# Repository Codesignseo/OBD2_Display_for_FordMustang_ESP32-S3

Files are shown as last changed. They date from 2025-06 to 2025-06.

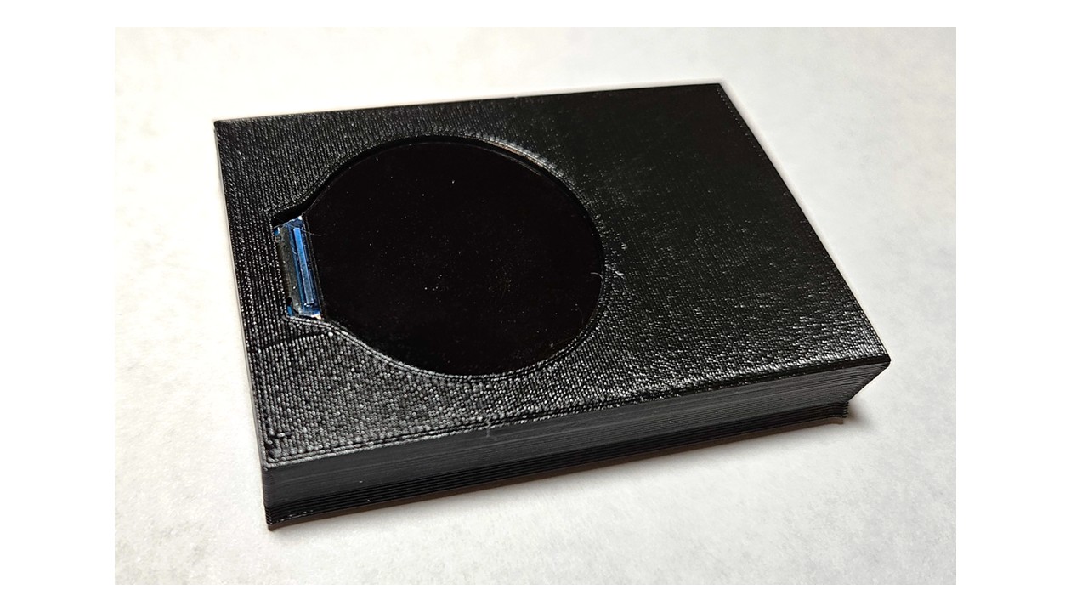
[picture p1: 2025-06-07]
Images/Design1.jpg

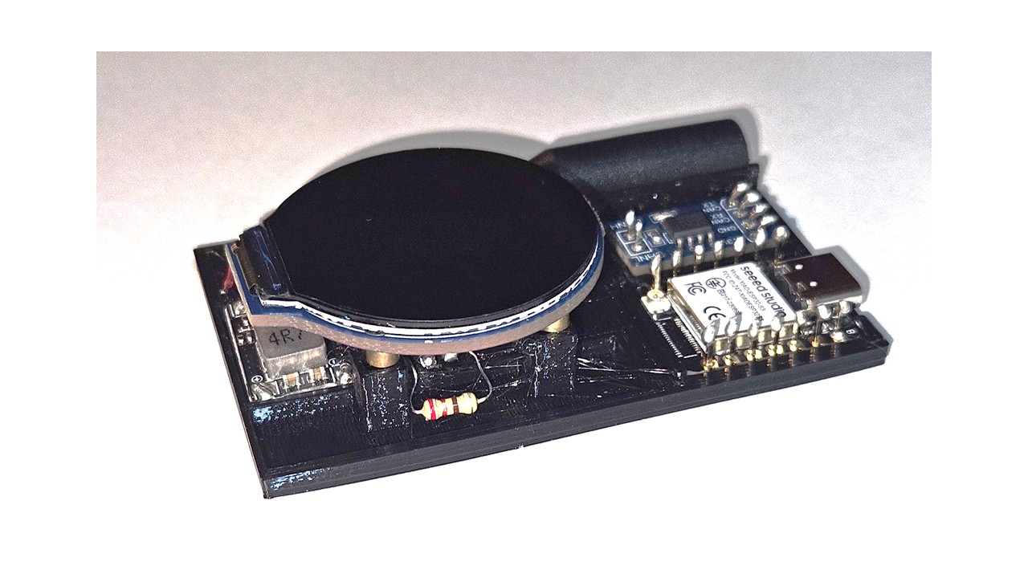
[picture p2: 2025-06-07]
Images/Design4.jpg

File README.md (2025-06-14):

# OBD2 Display for Ford Mustang ESP32-S3 🚗💨




Welcome to the OBD2 Display for Ford Mustang project! This Arduino-based project provides a sleek interface for displaying OBD2 data on a round LCD display. It is specifically designed for the 2016 Ford Mustang Ecoboost, offering real-time information about the currently selected gear and a simple gear shift indicator.

## Table of Contents

1. [Introduction](#introduction)
2. [Features](#features)
3. [Getting Started](#getting-started)
   - [Hardware Requirements](#hardware-requirements)
   - [Software Requirements](#software-requirements)
   - [Installation Instructions](#installation-instructions)
4. [Usage](#usage)
5. [Wiring Diagram](#wiring-diagram)
6. [Contributing](#contributing)
7. [License](#license)
8. [Contact](#contact)

## Introduction

The OBD2 Display for Ford Mustang project aims to enhance your driving experience by providing essential vehicle data at a glance. With this project, you can monitor your gear selection and RPM in real-time, ensuring you stay informed while on the road.

## Features

- **Real-time Gear Display**: See your current gear selection directly on the LCD.
- **Gear Shift Indicator**: Get a visual cue for when to shift gears.
- **Compact Design**: Fits seamlessly in your vehicle without cluttering the dashboard.
- **Easy Installation**: Simple wiring and setup make it accessible for all skill levels.

## Getting Started

To get started with the OBD2 Display for Ford Mustang project, follow these steps.

### Hardware Requirements

- **ESP32-S3**: The main microcontroller for this project.
- **Round LCD Display (GC9A01)**: For displaying the gear and RPM information.
- **OBD2 Adapter (SN65HVD230)**: To connect to the vehicle's OBD2 port.
- **MOSFET**: For controlling power to the display.
- **Wires and Connectors**: For making connections between components.
- **XIAO ESP32-S3**: A compact version of the ESP32-S3 for space-saving.

### Software Requirements

- **Arduino IDE**: Download and install the latest version of the Arduino IDE from the [official website](https://www.arduino.cc/en/software).
- **ESP32 Board Support**: Install the ESP32 board support in the Arduino IDE.
- **Libraries**: You will need the following libraries:
  - `OBD2 Library`
  - `GC9A01 Library`
  
### Installation Instructions

1. **Clone the Repository**: 
   Open your terminal and run:
   ```
   git clone https://github.com/Codesignseo/OBD2_Display_for_FordMustang_ESP32-S3.git
   ```
2. **Open the Project in Arduino IDE**: Navigate to the cloned folder and open the `.ino` file in the Arduino IDE.
3. **Install Required Libraries**: Go to `Sketch` > `Include Library` > `Manage Libraries`, and search for the required libraries mentioned above. Install them.
4. **Connect Your ESP32-S3**: Use a USB cable to connect your ESP32-S3 to your computer.
5. **Select the Correct Board**: In the Arduino IDE, go to `Tools` > `Board` and select `ESP32-S3`.
6. **Upload the Code**: Click on the upload button in the Arduino IDE to upload the code to your ESP32-S3.
7. **Download the Releases**: For the latest version of the software, visit the [Releases section](https://github.com/Codesignseo/OBD2_Display_for_FordMustang_ESP32-S3/releases) to download and execute the latest build.

## Usage

Once the setup is complete, you can start using the OBD2 Display. The LCD will automatically show the current gear and RPM as you drive. Adjust the display settings as needed through the Arduino IDE.

## Wiring Diagram

Here is a simple wiring diagram to help you connect the components:

```
ESP32-S3       Round LCD (GC9A01)
-----------------------------------
  GND  ------------------  GND
  3.3V ------------------  VCC
  GPIO23  --------------  SCL
  GPIO22  --------------  SDA

ESP32-S3       OBD2 Adapter (SN65HVD230)
------------------------------------------
  GND  ------------------  GND
  TX   ------------------  RX
  RX   ------------------  TX
```

## Contributing

We welcome contributions to this project. If you would like to contribute, please fork the repository and submit a pull request. Make sure to follow the coding standards and include tests for any new features.

## License

This project is licensed under the MIT License. See the [LICENSE](LICENSE) file for more details.

## Contact

For any questions or feedback, please reach out via the GitHub issues page or contact the repository owner directly.

Thank you for your interest in the OBD2 Display for Ford Mustang project! For the latest updates and releases, be sure to check the [Releases section](https://github.com/Codesignseo/OBD2_Display_for_FordMustang_ESP32-S3/releases).

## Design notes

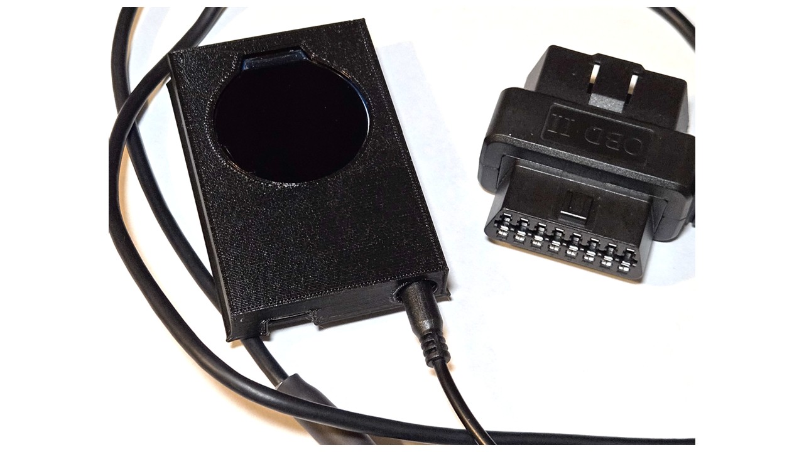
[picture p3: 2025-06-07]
Images/Design2.jpg

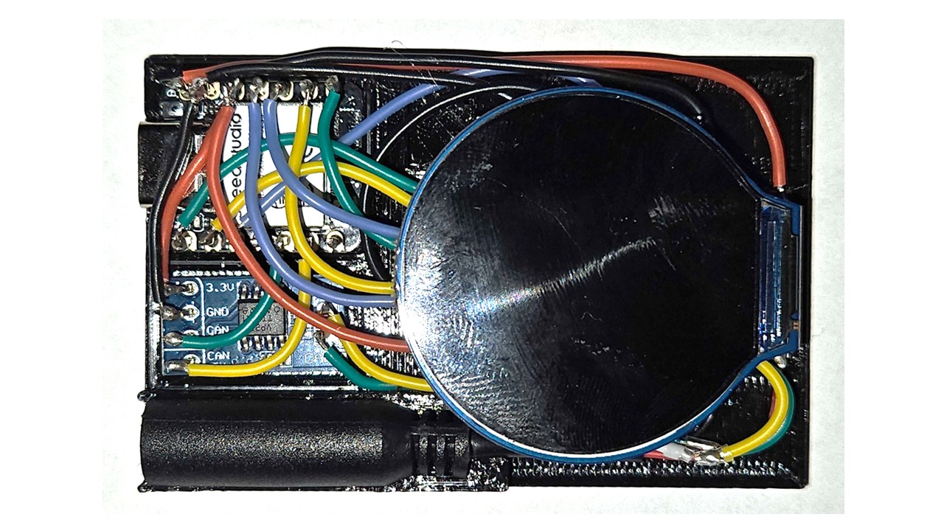
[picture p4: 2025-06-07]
Images/Design5.jpg

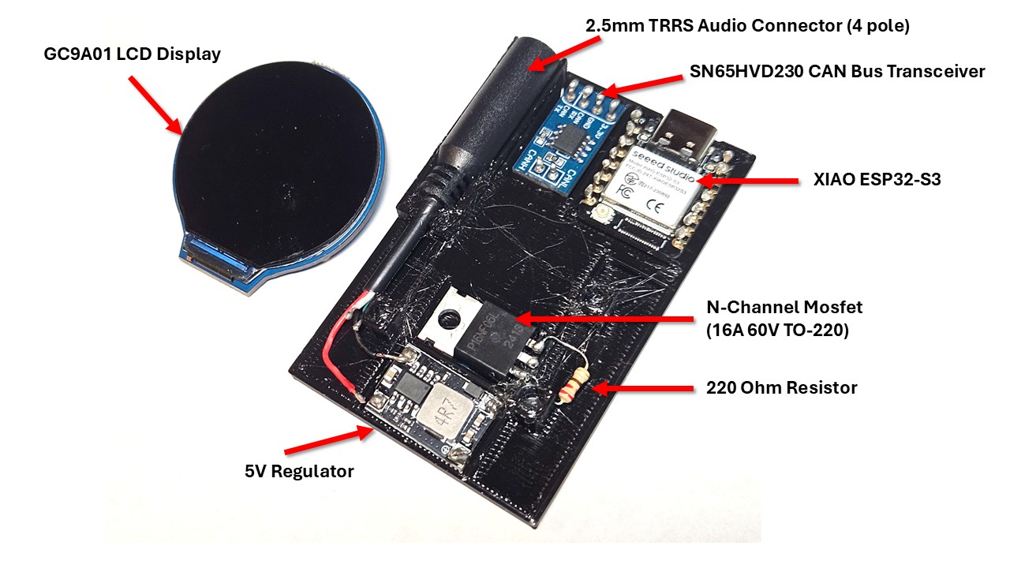
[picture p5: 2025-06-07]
Images/Design3.jpg

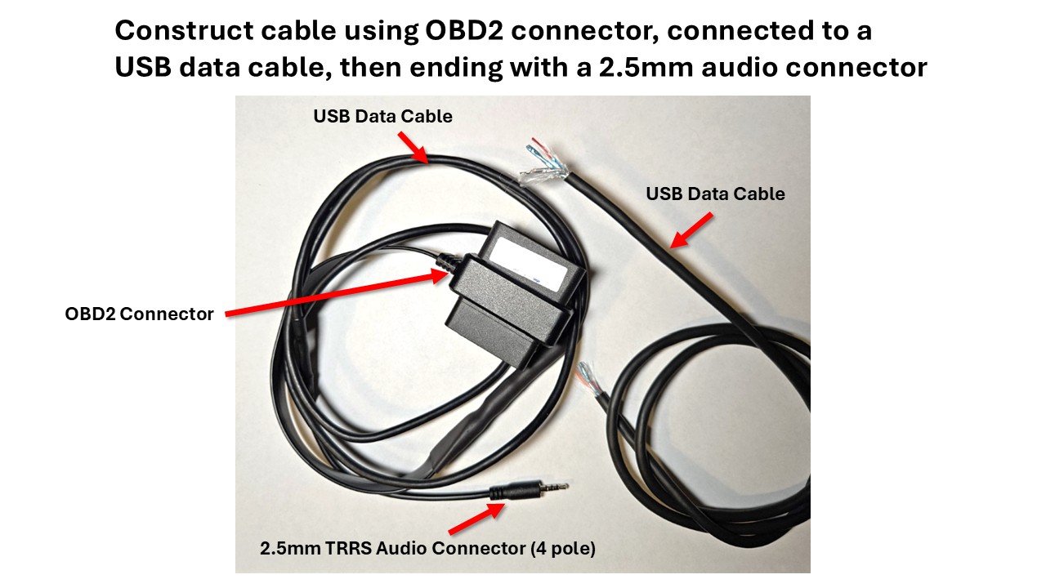
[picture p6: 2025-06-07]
Images/Design6.jpg

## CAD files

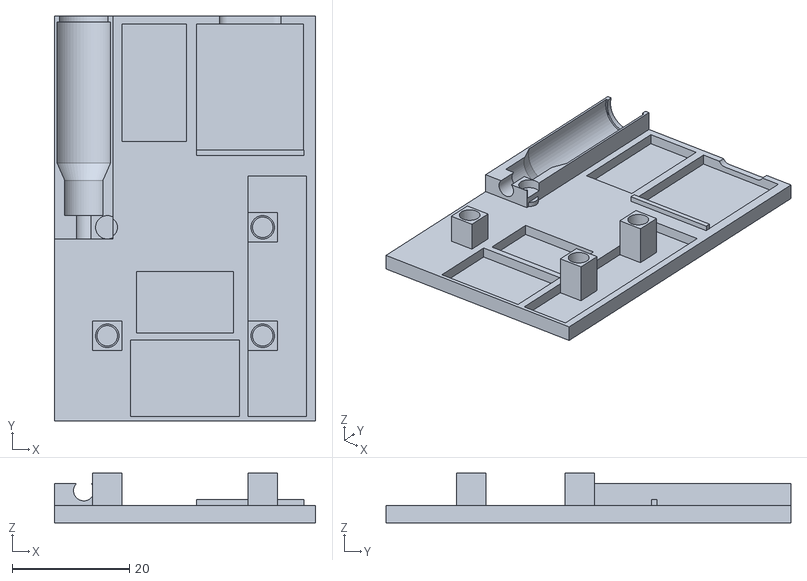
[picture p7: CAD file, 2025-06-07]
3DModels/Base.stl
44.5 x 69.0 x 8.50

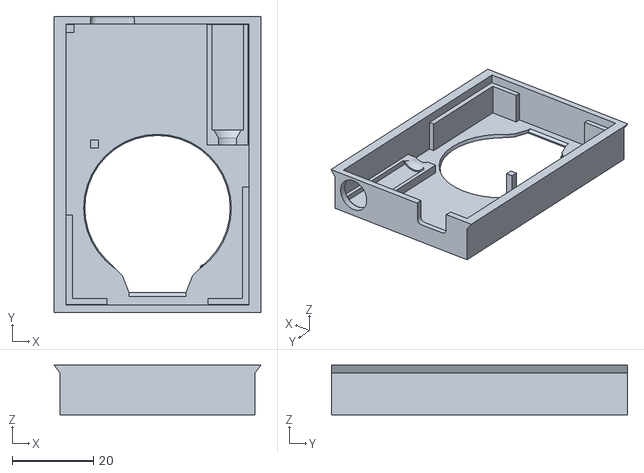
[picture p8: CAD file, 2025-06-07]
3DModels/Lid.stl
51.0 x 73.0 x 12.3

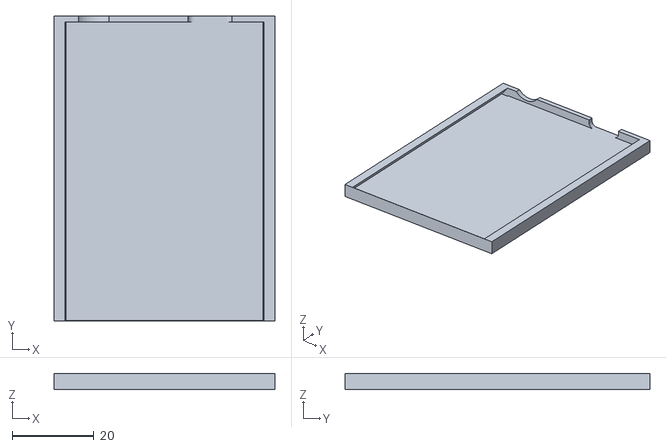
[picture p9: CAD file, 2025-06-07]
3DModels/DashboardMount.stl
54.0 x 74.5 x 4.00

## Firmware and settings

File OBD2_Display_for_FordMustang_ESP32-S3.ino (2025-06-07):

// An Arduino project for a 2016 Ford Mustang Ecoboost that uses OBD2 data and displays the currently selected gear and a simple gear shift indicator on a round LCD display.
//
// Hardware:
//    XIAO ESP32-S3
//    12V to 5V Voltage regulator
//    SN65HVD230 CAN bus transceiver
//    GC9A01 display
//    N-Channel Mosfet (16A 60V TO-220)
//    220 Ohm Resistor
//    2.5mm TRRS Audio Connector (4 pole)
//    OBD2 Connector
//    USB Data Cable
//    HUD Projective Film
//
// Arduino library used:
//    ESP32-TWAI-CAN: https://github.com/handmade0octopus/ESP32-TWAI-CAN
//    ArduinoGFX: https://github.com/moononournation/Arduino_GFX

// The final build should have this commented out
//#define DEBUG 1           // When this is defined, Serial input/output will happen, otherwise not
//#define DEBUG_RPM 1       // Allows for typing in numbers [0..7] in Serial Monitor to emulate RPM
//#define DEBUG_GEAR 1      // Allows for typing in numbers [0..7] in Serial Monitor to emulate current gear. This also requires DISABLE_POWER_SAVING

// The final build should have this commented out
// It's sometimes easier to debug without the device going into power save mode
//#define DISABLE_POWER_SAVING 1

// If we want to display the text on a projective film as a holographic effect on the windshield, then we need to mirror the text
#define MIRROR_TEXT_FOR_HOLOGRAPHIC_REFLECTION 1

#include "Shared.h"
#include "AsyncTimer.h"
#include "CollectCarData.h"
#include "DisplayInfo.h"
#include "HandleLowPowerState.h"

void setup()
{
  pinMode(LED_BUILTIN, OUTPUT);
  digitalWrite(LED_BUILTIN, LOW); // Turn on-board LED on

#ifdef DEBUG
  Serial.begin(115200);
  delay(200);
  Serial.printf("\n\n********* OBD2 Display for Ford Mustang using ESP32-S3 *********\n\n");
#endif

  // Device boots with 240Mhz clock speed. To save power we'll switch to 80Mhz, but just in case the device goes into a
  // reboot loop because of the lower clock, we delay for a few seconds, which will give time to reflash the program
  DebugPrintf("Clock frequency = %d\n", getCpuFrequencyMhz());
  DebugPrintf("Wait 4 seconds just in case device crashes with %dHz\n", ClockSpeed_LiteSleep);
  delay(4000);

  // Setup the CAN transceiver to receive CAN frames 
  SetupCollectCarData();

  // Wait until the car turns ON
  WaitForCarToTurnOn();

  // Create task that will display info using ESP32-S3 core 0
  xTaskCreatePinnedToCore(DisplayInfo, nullptr, 1024 * 128, nullptr, 1, &g_TaskDisplayInfo, 0);
}

void loop()
{
  CollectCarData();
  CheckIfCarIsStillOn();
}

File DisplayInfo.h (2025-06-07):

#ifndef _DISPLAY_INFO
#define _DISPLAY_INFO

#include <Arduino_GFX_Library.h>
#include "FreeMonoBold54pt7b.h"
#include "MirrorFont.h"
#include "AsyncTimer.h"

// Setup gfx library for the GC9A01 display
Arduino_DataBus* bus = new Arduino_ESP32SPI(GC9A01_DC, GC9A01_CS, GC9A01_SCK, GC9A01_MOSI, GC9A01_MISO);
Arduino_GFX* gfx = new Arduino_GC9A01(bus, GC9A01_RST, 0, true);
bool bIsDisplayOn = false;

// Define a simple shift indicator based only on RPM. It would be better to setup something using dyno numbers, looking at torque, etc.
struct ShiftIndicatorLights
{
  int32_t EngineRPM;
  uint16_t Color;
};

const int32_t NumLights = 5;
const int32_t ShiftNowIndex = 0;  // Index into shiftIndicatorLights for ideal shift time, i.e. when the indicator turns red
const ShiftIndicatorLights shiftIndicatorLights[NumLights] = { {4500, RED}, {3500, YELLOW}, {2500, GREEN}, {1500, BLUE}, {0, DARKGREY} };

const int32_t MaxRPM  = 6000;       // Max RPM to show on LCD
const int32_t Reverse = -1;         // Define Reverse as a special gear number
const int32_t Park    = -2;         // Define Park as a special gear number
int32_t  previousGear = -12;        // A randomly chosen initial number
uint16_t previousGearColor = WHITE;

// g_CurrentCarData is populated by the SN65HVD230 transceiver on another ESP32-S3 core. Since the data needs to be thread safe, we keep a
// local copy of the data on this thread, copying it safely using g_SemaphoreCarData
CarData carData;

// Make a local copy of car data that was gathered on the other ESP32-S3 core
void CopyCarData()
{
  xSemaphoreTake(g_SemaphoreCarData, portMAX_DELAY);
  memcpy(&carData, &g_CurrentCarData, sizeof(CarData));
  xSemaphoreGive(g_SemaphoreCarData);

  // If Neutral, then check if we're in Park, since we'd rather display "P" than "N" when in Park
  if (carData.CurrentGear == 0 &&
      carData.GearboxMode == GearboxMode::P)
  {
    carData.CurrentGear = Park;
  }
}

// Turn power for display ON
void TurnMosfetSwitchOn()
{
  DebugPrintln("Turn Mosfet switch ON");
  pinMode(MOSFET_GATE, OUTPUT);
  digitalWrite(MOSFET_GATE, HIGH);
}

// Turn power for display OFF
void TurnMosfetSwitchOff()
{
  DebugPrintln("Turn Mosfet switch OFF");
  pinMode(MOSFET_GATE, OUTPUT);
  digitalWrite(MOSFET_GATE, LOW);
}

void TurnDisplayOn()
{
  DebugPrintln("TurnDisplayOn()");

  // Turn power on
  TurnMosfetSwitchOn();

  // Init display
  while (!gfx->begin())
  {
    DebugPrintln("gfx->begin() failed!");
    delay(500);
  }

  bIsDisplayOn = true;

  gfx->fillScreen(RGB565_BLACK);
  gfx->setRotation(2);
  gfx->setFont(&FreeMonoBold54pt7b);
  gfx->setTextSize(2);
}

void TurnDisplayOff()
{
  DebugPrintln("TurnDisplayOff()");
  gfx->fillScreen(RGB565_BLACK);
  TurnMosfetSwitchOff();
  bIsDisplayOn = false;
  delay(200);
}

// This will be called from the main setup() function, which will get called each time the device wakes up from deep sleep
void SetupDisplay()
{
  DebugPrintln("SetupDisplay()");

  // If we want to display the text on a projective film as a holographic effect on the windshield, then we need to mirror the text
#ifdef MIRROR_TEXT_FOR_HOLOGRAPHIC_REFLECTION
  const uint8_t fontStartCharacter = FreeMonoBold54pt7b.first;

  // Mirror text: P, R, N, 0-9 (takes only ~15ms)
  uint16_t index = 'P' - fontStartCharacter;
  MirrorText(FreeMonoBold54pt7bBitmaps, FreeMonoBold54pt7bGlyphs[index].bitmapOffset,  FreeMonoBold54pt7bGlyphs[index].width, FreeMonoBold54pt7bGlyphs[index].height);
  index = 'R' - fontStartCharacter;
  MirrorText(FreeMonoBold54pt7bBitmaps, FreeMonoBold54pt7bGlyphs[index].bitmapOffset,  FreeMonoBold54pt7bGlyphs[index].width, FreeMonoBold54pt7bGlyphs[index].height);
  index = 'D' - fontStartCharacter;
  MirrorText(FreeMonoBold54pt7bBitmaps, FreeMonoBold54pt7bGlyphs[index].bitmapOffset,  FreeMonoBold54pt7bGlyphs[index].width, FreeMonoBold54pt7bGlyphs[index].height);
  index = 'N' - fontStartCharacter;
  MirrorText(FreeMonoBold54pt7bBitmaps, FreeMonoBold54pt7bGlyphs[index].bitmapOffset,  FreeMonoBold54pt7bGlyphs[index].width, FreeMonoBold54pt7bGlyphs[index].height);

  for (int i = 0; i < 10; i++)
  {
    index = '0' + i - fontStartCharacter;
    MirrorText(FreeMonoBold54pt7bBitmaps, FreeMonoBold54pt7bGlyphs[index].bitmapOffset,  FreeMonoBold54pt7bGlyphs[index].width, FreeMonoBold54pt7bGlyphs[index].height);
  }
#endif
}

char GenerateGearText(const int32_t gear)
{
  if ((gear > 0) && (gear <= 8))
  {
    return '0' + gear;
  }
  else
  {
    return (gear == Park) ? 'P' : (gear == Reverse) ? 'R' : (gear == 0) ? 'N' : 'D';
  }
}

// Clear the current gear text by redrawing it in black
void ClearGearText(const int32_t gear)
{
  gfx->setCursor(60, 180);
  gfx->setTextColor(RGB565_BLACK);
  gfx->printf("%c", GenerateGearText(gear));
}

void DrawGearText()
{
  // Determine and keep track of the gear color
  uint16_t color = WHITE;
  if (carData.EngineRPM > shiftIndicatorLights[ShiftNowIndex].EngineRPM)
  {
    color = RED;
  }

  // Update the text when the gear changes
  if (carData.CurrentGear != previousGear)
  {
    ClearGearText(previousGear);

    // Show the new gear
    gfx->setCursor(60, 180);
    gfx->setTextColor(color);
    gfx->printf("%c", GenerateGearText(carData.CurrentGear));

    previousGear = carData.CurrentGear;
    previousGearColor = color;
  }

  // Update the text when the gear color changes
  if (color != previousGearColor)
  {
    // Show the current gear with the new color
    gfx->setCursor(60, 180);
    gfx->setTextColor(color);
    gfx->printf("%c", GenerateGearText(carData.CurrentGear));

    previousGearColor = color;
  }
}

void DrawShiftIndicator()
{
  uint16_t color = DARKGREY;

  for (int i = 0; i < NumLights; i++)
  {
    if (carData.EngineRPM > shiftIndicatorLights[i].EngineRPM)
    {
      color = shiftIndicatorLights[i].Color;
      break;
    }
  }

  const uint16_t rotate = 90;
  const uint16_t endRadius = (min(MaxRPM, carData.EngineRPM) / float(MaxRPM)) * 180.0f;

  // Draw left side bar
  gfx->fillArc(120, 120, 120, 95, 0 + rotate, endRadius + rotate, color);
  gfx->fillArc(120, 120, 120, 95, endRadius + rotate, 180 + rotate, BLACK);

  // Draw right side bar
  gfx->fillArc(120, 120, 120, 95, 360 - endRadius + rotate, 360 + rotate, color);
  gfx->fillArc(120, 120, 120, 95, 360 - 180 + rotate, 360 - endRadius + rotate, BLACK);
}

// Main function of the thread task running on a seperate ESP32-S3 core
void DisplayInfo(void* params)
{
  DebugPrintf("Core %d: DisplayInfo()\n", xPortGetCoreID());

  SetupDisplay();
  TurnDisplayOn();

  while (true)
  {
    CopyCarData();

    if (bIsDisplayOn)
    {
      DrawGearText();
      DrawShiftIndicator();
    }

    delay(1);  // Make sure something is happening on the thread, otherwise a watchdog timer will kick in after 5 seconds and reboot device
  }
}

#endif  // _DISPLAY_INFO
